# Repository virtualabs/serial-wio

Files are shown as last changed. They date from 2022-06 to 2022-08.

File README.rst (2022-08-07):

Serial-Wio
==========

Turn your WioTerminal into an automagic UART terminal !

Features
--------

* Automatic baudrate/parity detection
* On-screen UART log
* USB UART bridge

Case printing and assembly
--------------------------

A custom case has been designed to fit the WioTerminal, it allows normal multimeter probes
to be used and protects the electronics.

The case is made of 3 independent parts that may be 3d printed with any decent 3d printer:

* a bottom part that holds 6 M3 hex screws
* a middle part that holds 2 M3 hex nuts
* a top part

Extra materials required:

* 2x 10mm M3 screws
* 4x 15mm M3 screws
* 2x M3 nuts

Printing the case
~~~~~~~~~~~~~~~~~

Top part must be printed upside down to get best results, without supports. Bottom part must be
printed with supports to get the screws' heads holes correctly printed.

Assembling the case
~~~~~~~~~~~~~~~~~~~

First, insert 2x 10mm M3 screws in the bottom part as shown below:

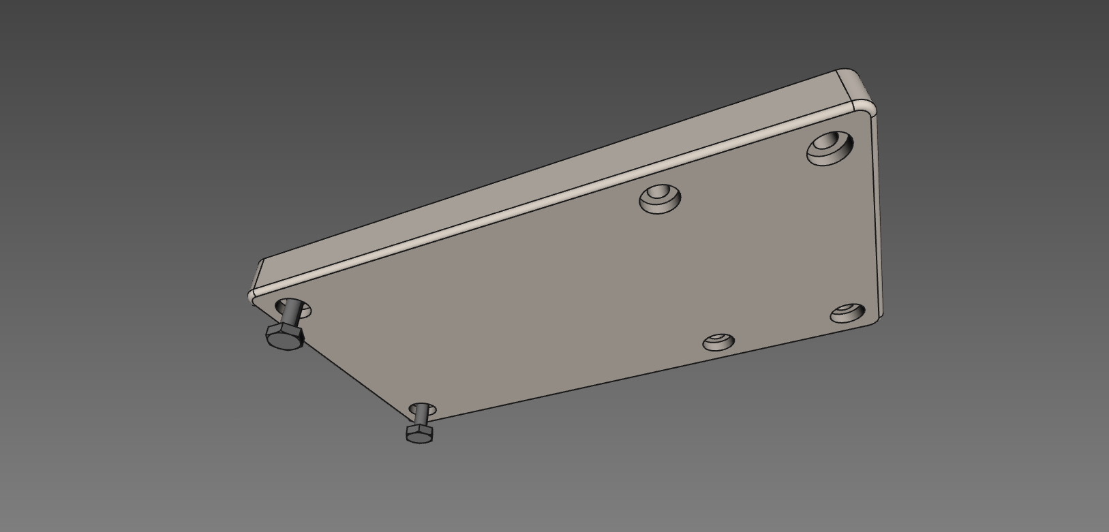
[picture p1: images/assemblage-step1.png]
Assembling bottom part


Then, place the custom PCB inside the bottom part:

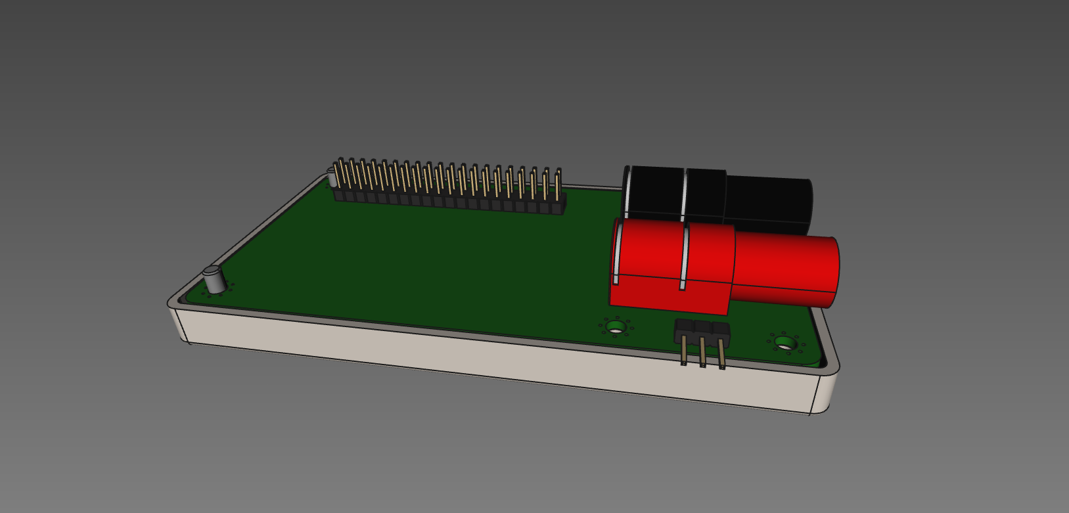
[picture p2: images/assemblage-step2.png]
Insert Serial-Wio assembled PCB


Place on top of this the intermediate lid and add two M3 nuts. Tighten them just enough to hold the lid
in place. 

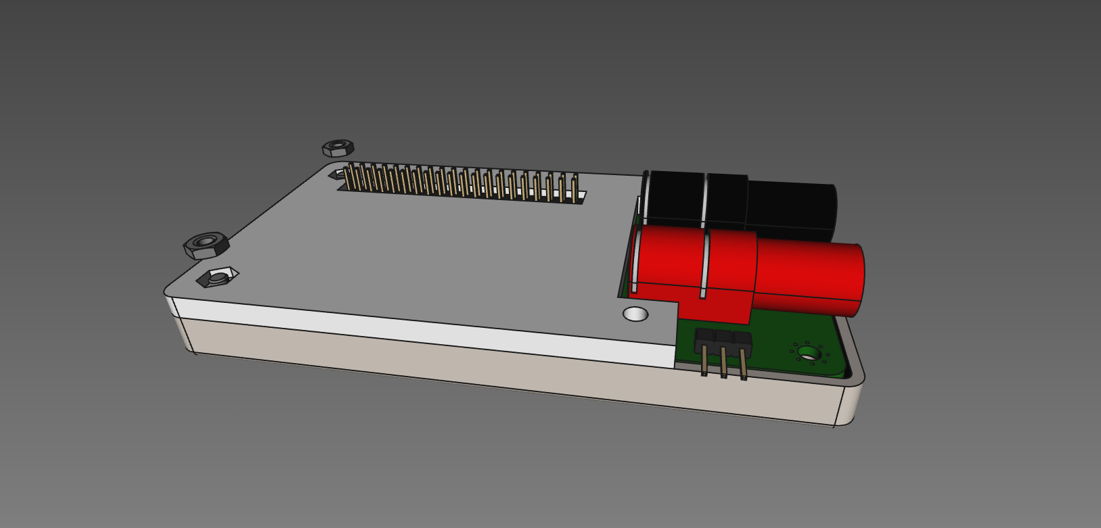
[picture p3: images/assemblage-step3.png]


Last, place the top lid and screw 4x 15mm M3 screws to maintain it in place, as shown below:

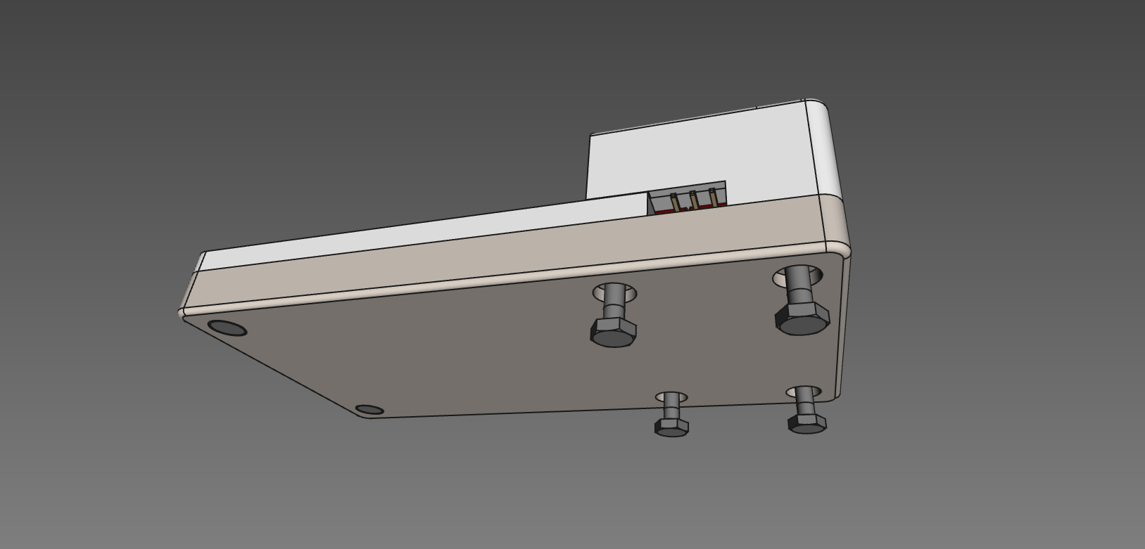
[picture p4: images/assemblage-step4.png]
Fix the top lid


You can now connect your WioTerminal to your SerialWio module:

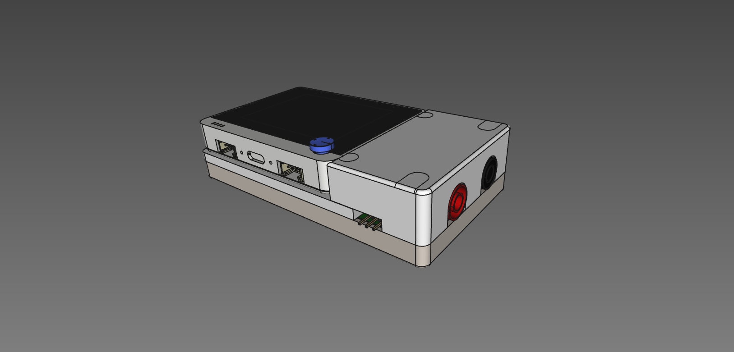
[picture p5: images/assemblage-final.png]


Custom PCB
----------

We designed a custom PCB that extends WioTerminal capabilities designed with KiCAD v5.
Design files are available in `PCB_design_files` folder, including 3D models and custom
fingerprints.

Gerber files
~~~~~~~~~~~~

Gerber files are also provided in the `PCB_design_files/gerber` directory, as well as the
`kicad_pcb` file if you want to order it on OSHPark. 

Bill of materials
~~~~~~~~~~~~~~~~~

* Q1, Q2, Q3: SOT23 MMBF170 N-channel MOSFET 60V 225mW (Ref LCSC: C130879)
* R1, R2, R3: R0805 10 Kohm (Ref LCSC: C269742)
* TEST_SIG1: 4mm banana female plug red (Farnell: SWEB 8094 AU/RT)
* TEST_GND1: 4mm banana female plug black (Farnell: SWEB 8094 AU/SW)
* 3 contacts (1 row) 2.54mm right-angled header

Software dependencies
---------------------

First, you need to follow the `Get Started with Wio Terminal <https://wiki.seeedstudio.com/Wio-Terminal-Getting-Started/>`_
guide in order to setup your Arduino development environment.

This project has been designed with Arduino and requires some libraries to successfully compile:

* `TFT_eSPI` to drive the LCD screen of the WioTerminal
* `SAMD_TimerInterrupt` to handle SAMD21 timers

Make sure to add them before trying to compile the import the Arduino sketch and build it (use Arduino's
library manager).

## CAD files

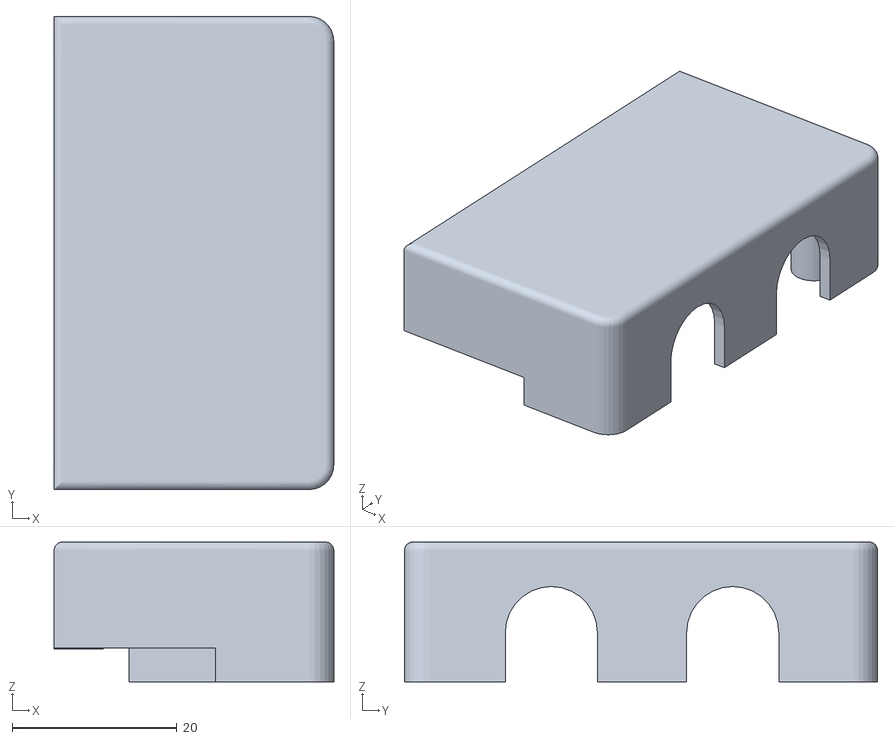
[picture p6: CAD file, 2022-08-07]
Case_design_files/case-top-part.stl
34.0 x 57.5 x 17.0

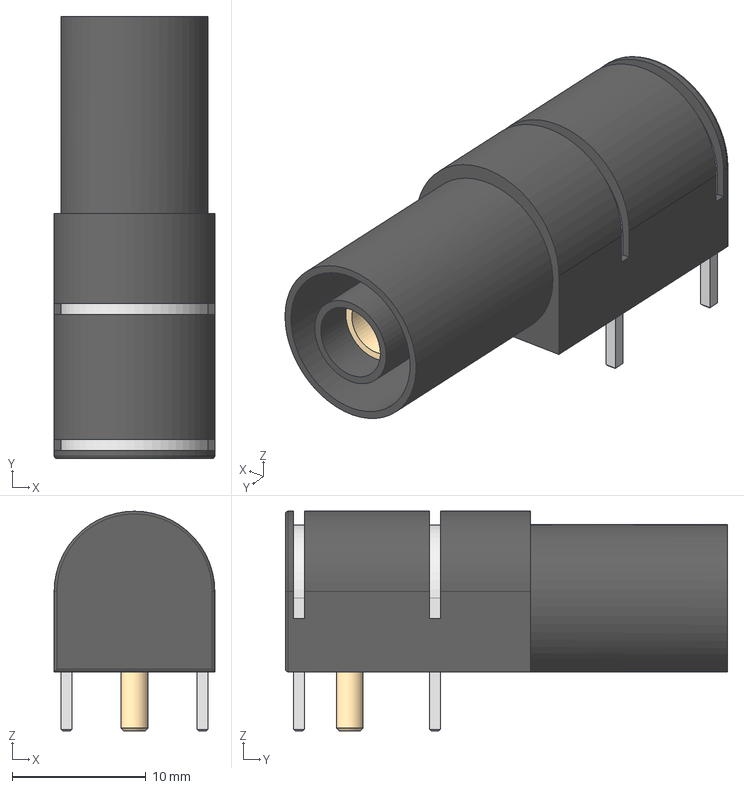
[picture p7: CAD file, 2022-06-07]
PCB_design_files/3d/4mm-test-conn-socket-black.step
12.0 x 33.0 x 16.4 mm
Corps principal
Anneau intérieur
Pin verticale 1
Pin verticale 2
Pin principale

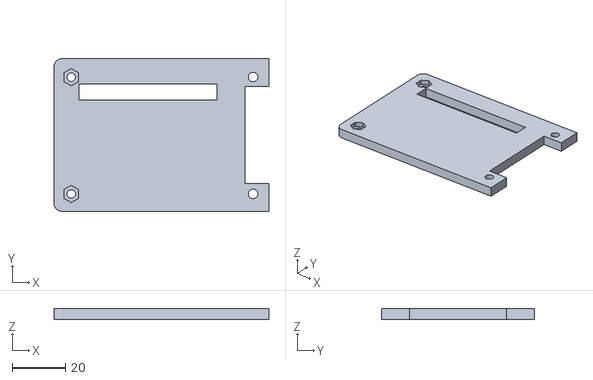
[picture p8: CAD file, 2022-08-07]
Case_design_files/case-intermediate-lid-part.stl
81.0 x 57.5 x 4.00

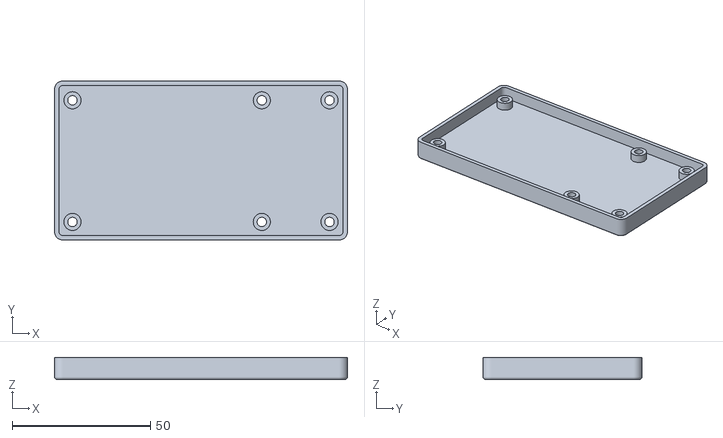
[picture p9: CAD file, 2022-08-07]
Case_design_files/case-bottom-part.stl
106.0 x 57.5 x 8.00

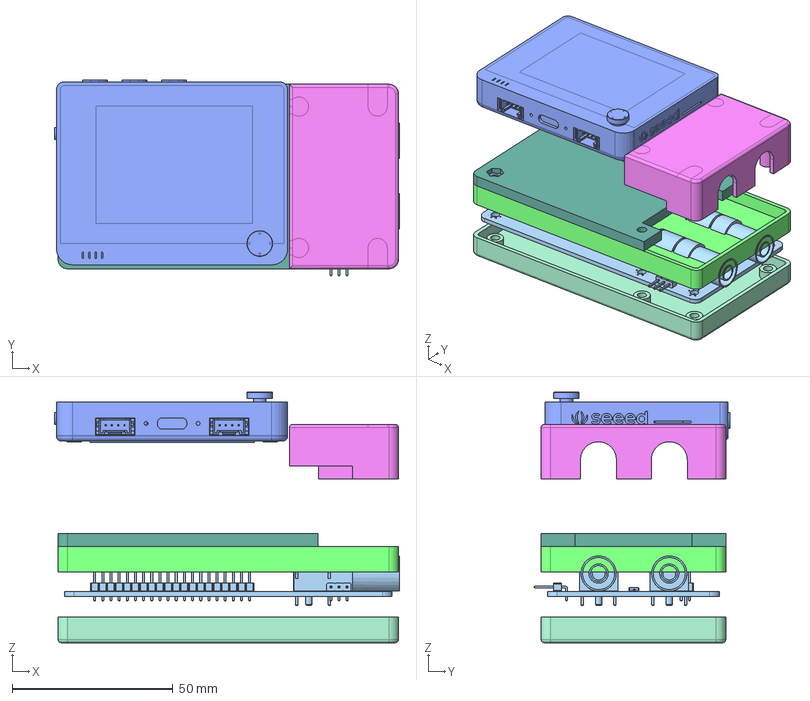
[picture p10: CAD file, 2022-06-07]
Case_design_files/serial-wio-case.FCStd
107.4 x 60.9 x 78.0 mm
Wio Terminal
Capot intermédiaire
Capot connecteurs
Pocket008Body
serial-wio

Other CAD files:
PCB_design_files/3d/4mm-test-conn-socket-red.step
PCB_design_files/3d/4mm-test-conn-socket.step
PCB_design_files/3d/4mm-test-conn-socket.FCStd

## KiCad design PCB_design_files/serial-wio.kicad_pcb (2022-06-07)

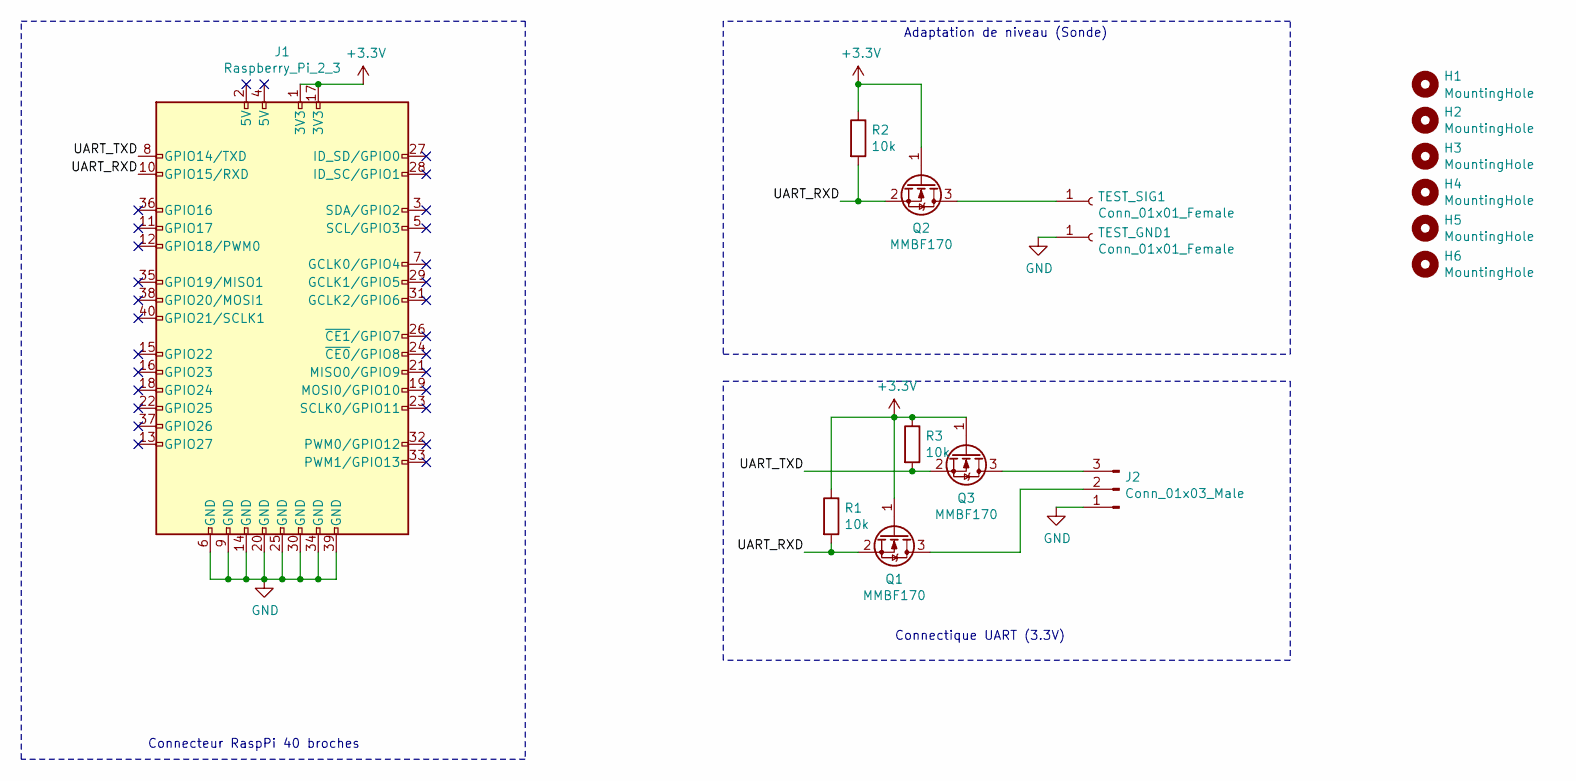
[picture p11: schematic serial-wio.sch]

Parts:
H1, H2, H3, H4, H5, H6: MountingHole; MountingHole_3.2mm_M3_Pad_Via
J1: Raspberry_Pi_2_3; PinHeader_2x20_P2.54mm_Vertical
J2: Conn_01x03_Male; PinHeader_1x03_P2.54mm_Horizontal
Q1, Q2, Q3: MMBF170; SOT-23
R1, R2, R3: 10k; R_0805_2012Metric
TEST_GND1: Conn_01x01_Female; 4mm-test-conn-socket
TEST_SIG1: Conn_01x01_Female; 4mm-test-conn-socket

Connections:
+3V3: J1.1 (3V3), J1.17 (3V3), Q1.1 (G), Q2.1 (G), Q3.1 (G), R1.1, R2.1, R3.1
/UART_RXD: J1.10 (GPIO15/RXD), Q1.2 (S), Q2.2 (S), R1.2, R2.2
/UART_TXD: J1.8 (GPIO14/TXD), Q3.2 (S), R3.2
GND: J1.6 (GND), J1.9 (GND), J1.14 (GND), J1.20 (GND), J1.25 (GND), J1.30 (GND), J1.34 (GND), J1.39 (GND), J2.1, TEST_GND1.1
unnamed: J2.2, Q1.3 (D)
unnamed: J2.3, Q3.3 (D)
unnamed: Q2.3 (D), TEST_SIG1.1

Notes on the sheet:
Connecteur RaspPi 40 broches
Adaptation de niveau (Sonde)
Connectique UART (3.3V)

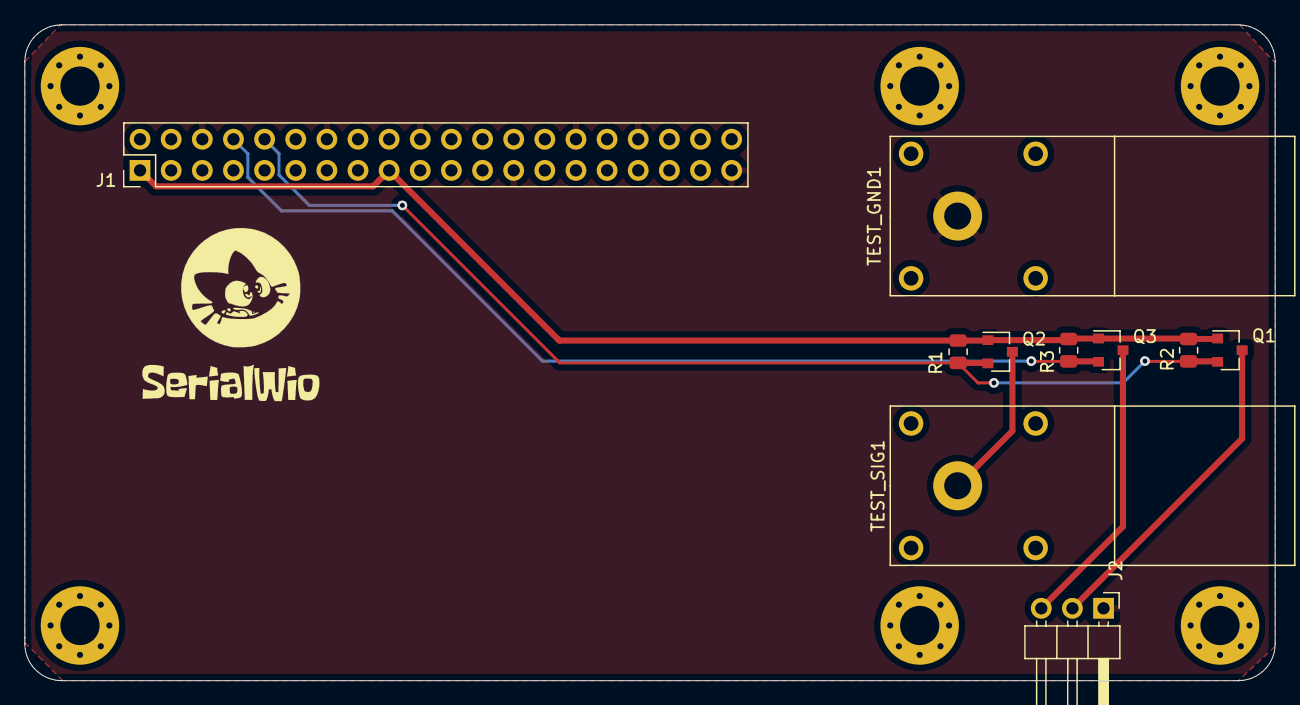
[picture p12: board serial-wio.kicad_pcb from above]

Board: 2 copper layers, 102.0 x 53.5 mm, 17 parts (0 on the bottom side), 7 nets.

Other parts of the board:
kibuzzard-62313C45: G***; label

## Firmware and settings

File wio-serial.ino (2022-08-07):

#include "SAMDTimerInterrupt.h"
#include"TFT_eSPI.h"

#define BUZZER_PIN WIO_BUZZER /* sig pin of the buzzer */

#define MAX_MEASURES    5000
#define IDLE_INTERVAL   100000
#define PROBE_INPUT     PIN_SERIAL1_RX
#define SCREEN_WIDTH    50
#define SCREEN_HEIGHT   22
#define LINE_HEIGHT     10
#define LOG_OFFSET_Y    (2*LINE_HEIGHT)

#define BG_COLOR        TFT_BLACK
#define TEXT_COLOR      TFT_LIGHTGREY

/*********************
 * Typedefs
 *********************/

typedef enum {
  WAITING,
  ACQUIRE,
  ANALYZE,
  MONITOR
} mp_state_t;

enum {
  PAR_NONE = 0,
  PAR_ODD,
  PAR_EVEN,
  PAR_MAX
};

typedef struct {
  int period;
  int baudrate;
} baudrate_info_t;

/**********************
 * Globals
 **********************/

/* Global state. */
volatile mp_state_t g_state;

/* Logic analysis. */
static uint32_t g_measures[MAX_MEASURES];
volatile uint32_t g_usec_counter;
volatile uint32_t g_last_timestamp;
volatile int g_nb_measures;
volatile int baudrate = 0, uart_config, good_par, g_bytesize;

/* Timer. */
SAMDTimer ITimer0(TIMER_TC3);

/* Screen. */
TFT_eSPI tft;
char g_uart_log[SCREEN_HEIGHT][SCREEN_WIDTH+1];
int g_uart_cur_col, g_uart_cur_line, g_uart_top_line;



/**********************************************
 **********************************************
 *
 * Helpers
 * 
 **********************************************
 **********************************************/

/**
 * @brief Convert period to standard baudrate
 * @param period: measured period in microseconds
 * @return closest standard baudrate
 */
int period_to_baudrate(int period)
{
  int i=0;
  baudrate_info_t rates[] = {
    {4, 230400},
    {8, 115200},
    {13, 76800},
    {17, 57600},
    {26, 38400},
    {34, 28800},
    {52, 19200},
    {104, 9600},
    {0, 0}
  };

  while (rates[i].period > 0)
  {
    if ( period <= (rates[i].period+1))
    {
      return rates[i].baudrate;
    }
    i++;
  }

  /* Not found, return -1. */
  return -1;
}


/**
 * @brief Count printable characters
 * @param p_data: pointer to an array of characters
 * @param data_size: number of characters in the given array
 * @return number of printable characters
 */

int count_printable_chars(char *p_data, int data_size)
{
  int count=0;
  for (int i=0; i<data_size; i++)
  {
    if (isPrintable(p_data[i]))
      count++;
  }

  return count;
}


/**
 * @brief uSec counter callback (used for logic analysis).
 **/

void u_sec_counter(void)
{
  /* Increment our counter. */
  g_usec_counter++;

  /* Detect if we detect an idling UART. */
  if ((g_state == ACQUIRE) && ((g_usec_counter - g_last_timestamp) > IDLE_INTERVAL))
  {
    g_state = ANALYZE;
  }
}

/**
 * @brief Play tone.
 * @param tone: tone to play (Hz)
 * @param duration: tone duration (milliseconds)
 **/

void playTone(int tone, int duration) {
    for (long i = 0; i < duration * 1000L; i += tone * 2) {
        digitalWrite(BUZZER_PIN, HIGH);
        delayMicroseconds(tone);
        digitalWrite(BUZZER_PIN, LOW);
        delayMicroseconds(tone);
    }
}


/**********************************************
 **********************************************
 *
 * Screen management
 * 
 **********************************************
 **********************************************/

/**
 * @brief Clear UART log screen
 */

void clear_log_screen(void)
{
  /* Clear screen buffer. */
  memset(g_uart_log, 0, (SCREEN_WIDTH+1)*SCREEN_HEIGHT);
  g_uart_cur_line = 0;
  g_uart_cur_col = 0;
  g_uart_top_line = 0;

  /* Clear screen. */
  tft.fillRect(0, LOG_OFFSET_Y, 320, 240 - LOG_OFFSET_Y, BG_COLOR);
}


/**
 * @brief Update status bar (in MONITOR mode)
 */
 
void update_status_bar(void)
{
  char parity[] = "NOE";
  char sz_baudrate[10];
  char sz_config[4];
  snprintf(sz_baudrate, 10, "%d", baudrate);
  snprintf(sz_config, 4, "%d%c1", g_bytesize, parity[good_par]);
  
  tft.fillRect(0, 0, 320, LOG_OFFSET_Y-2, TFT_DARKGREEN);
  tft.setTextSize(2);
  tft.drawString(sz_baudrate, 5, 2);
  tft.drawString(sz_config, 90, 2);
  tft.setTextSize(1);
}


/**
 * @brief Update measures bar (in WAITING mode)
 */
 
void update_waiting_measures(void)
{
  int prog = (g_nb_measures * 150.0)/MAX_MEASURES;
  tft.drawRect(85, 125, 150, 10, TFT_NAVY);
  tft.fillRect(86, 126, prog,8, TFT_NAVY);
}


/**
 * @brief Update our waiting screen (in WAITING mode)
 */
 
void wait_screen(void)
{
  tft.fillRect(0, 0, 320, 240,BG_COLOR);
  tft.fillRect(80, 90, 160, 60, TFT_DARKGREY);
  tft.setTextSize(2);
  tft.drawString("Syncing ...", 85, 95);
  tft.setTextSize(1);

  update_waiting_measures();
}


/**********************************************
 **********************************************
 *
 * User button callbacks
 * 
 **********************************************
 **********************************************/

/**
 * @brief Resync button callback
 **/
 
void resync_button_pressed(void)
{
  /* No effect if we are currently syncing ... */
  if (g_state == WAITING)
    return;
  
  /* Debounce */
  delay(10);
  if (digitalRead(WIO_KEY_C) != 0)
    return;
  
  /* Setup our input GPIO. */
  Serial1.end();
  attachInterrupt(digitalPinToInterrupt(PROBE_INPUT), track_state, CHANGE);
  
  /* Restart analysis. */
  g_state = WAITING;

  /* Reset measures. */
  g_nb_measures = 0;

  /* Reset counter. */
  g_usec_counter = 0;
  g_last_timestamp = 0;

  /* Reset screen. */
  wait_screen();
}


/**
 * @brief Clear screen button callback
 **/

void clear_button_pressed(void)
{
  if (g_state == MONITOR)
  {
    /* Debounce */
    delay(10);
    if (digitalRead(WIO_KEY_A) != 0)
      return;

    clear_log_screen();
  }
}


/**********************************************
 **********************************************
 *
 * Signal acquisition callback (timer)
 * 
 **********************************************
 **********************************************/

/**
 * @brief Track state of input probe.
 * 
 * Fills g_measures with timestamps.
 */

void track_state(void)
{
  switch(g_state)
  {
    case WAITING:
      {
        /* Found a falling edge, start acquisition. */
        if (digitalRead(PROBE_INPUT) == 0)
        {
          /* Save measure. */
          g_nb_measures = 0;
          g_measures[g_nb_measures++] = g_usec_counter;
          g_last_timestamp = g_usec_counter;
          
          /* Set mode to ACQUIRE. */
          g_state = ACQUIRE;
        }
      }
      break;

    case ACQUIRE:
      {
        /* Save measure if we have enough memory. */
        if (g_nb_measures < MAX_MEASURES)
        {
          /* Save measure. */
          g_measures[g_nb_measures++] = g_usec_counter;
          g_last_timestamp = g_usec_counter;
        }
        else
        {
          Serial.println("> Switching to analysis");
          /* Switch to analyze mode. */
          g_state = ANALYZE;
        }
      }
      break;
  }
}
 

/**********************************************
 **********************************************
 *
 * Main code
 * 
 **********************************************
 **********************************************/

/**
 * @brief Setup routine (initializes the WioTerminal)
 */
 
void setup() {
  /* Setup WioTerminal Serial. */
  Serial.begin(115200);

  /* Setup screen. */
  tft.begin();
  tft.setRotation(3);
  tft.fillScreen(BG_COLOR); //Red background
  tft.setTextColor(TEXT_COLOR);          //sets the text colour to black
  tft.setTextSize(1);                   //sets the size of text

  /* Clear screen. */
  clear_log_screen();

  /* Setup our buttons. */
  pinMode(WIO_KEY_A, INPUT_PULLUP);
  pinMode(WIO_KEY_C, INPUT_PULLUP);
  attachInterrupt(digitalPinToInterrupt(WIO_KEY_A), clear_button_pressed, FALLING);
  attachInterrupt(digitalPinToInterrupt(WIO_KEY_C), resync_button_pressed, FALLING);
 
  /* Setup our input GPIO. */
  Serial1.end(); // Disable hardware UART
  pinMode(PROBE_INPUT, INPUT);
  attachInterrupt(digitalPinToInterrupt(PROBE_INPUT), track_state, CHANGE);

  /* Setup our buzzer. */
  pinMode(WIO_BUZZER, OUTPUT);

  /* Set default state. */
  mp_state_t g_state = WAITING;
  g_nb_measures = 0;

  /* Set our timer. */
  g_usec_counter = 0;

  /* Start timer (call u_sec_counter each microsecond. */
  ITimer0.attachInterruptInterval(1, u_sec_counter);

  /* Display wait screen. */
  wait_screen();
}


/**
 * @brief Try to decode a captured signal based on possible UART parameters.
 * @param period: period used to reconstruct the UART frame (number of samples per bit)
 * @param nbits: number of bits to code 1 'byte'
 * @param bit_duration: duration of 1 bit in microsecond (used to compute baudrate)
 * @param parity: parity (none, odd, even)
 * @param p_data: pointer to an output buffer
 * @param p_data_size: pointer to the size of the output buffer
 * @return number of encountered errors.
 */
 
int try_decode(int period, int nbits, int bit_duration, int parity, char *p_data, int *p_data_size)
{
  int i,j,bitpos,m,ones,errors;
  uint8_t state=1;
  uint8_t bits[10];
  unsigned char b;
  uint32_t tzero;
  bool b_parity_enabled = false;
  int nbytes;
  
  enum {
    START,
    DATA,
    PARITY,
    STOP
  };
  
  uint8_t decode_state = STOP;
    
  /* bit duration. */
  //const double t = 1000000.0/baudrate;
  const double t = bit_duration;
  double t_off = 0.0;
  tzero = g_measures[0]; /* timestamp du startbit, en usec */

  /* Determine parity bit size. */
  if (parity != PAR_NONE)
  {
    b_parity_enabled = true;
  }
  
  /* No errors encountered yet. */
  errors = 0;
  nbytes = 0;

  i=0;
  m=0;
  t_off = tzero;
  while (m < g_nb_measures)
  {
    /* track state change. */
    if (t_off >= g_measures[m])
    {
      /* Tuning. */
      tzero = g_measures[m];
      i = 0;
      
      //Serial.println("-- state change detected");
      state = (~state)&1;
      m++;
      
      /* Falling edge: start bit. */
      if ((decode_state == STOP) && !state)
      {
        //Serial.println("Falling edge, start bit detected.");
        decode_state = START;
      }
    }
    
    /* save bit. */
    if (t_off > (tzero + i*t + t/2) )
    {
      switch(decode_state)
      {
        case DATA:
          {
            bits[bitpos++] = state;

            if (bitpos >= (nbits + ((b_parity_enabled)?1:0)))
            {
              /* parity not supported yet, goto stop bit. */
              decode_state = STOP;

              /* Decode byte and display. */
              b=0;
              ones=0;
              for (j=0; j<nbits; j++)
              {
                /* Count 1's. */
                if (bits[j]&1)
                  ones++;

                /* Compute byte. */
                b |= ((bits[j]&1) << j);
              }

              /* Check parity if required. */
              if (b_parity_enabled)
              {
                switch(parity)
                {
                  case PAR_ODD:
                    {
                      if (bits[nbits] != ((ones%2)==0)?1:0)
                        errors++;
                    }
                    break;

                  case PAR_EVEN:
                    {
                      if (bits[nbits] != (ones%2))
                        errors++;
                    }
                    break;
                  
                  default:
                    break;
                }
              }

              /* Save decoded byte. */
              if (nbytes < *p_data_size)
              {
                p_data[nbytes++] = b;
              }
              else
              {
                /* Return the number of bytes written. */
                *p_data_size = nbytes;
              
              
                /* Return number of errors. */
                return errors;
              }
              
            }
          }
          break;
          
          
        case START:
          {
            decode_state = DATA;
            bitpos = 0;
          }
          break;

        default:
          break;
      }

      i++;
    }
    
    t_off += period;
  }

  /* Return the number of bytes written. */
  *p_data_size = nbytes;


  /* Return number of errors. */
  return errors;
}

/**
 * Main loop.
 */

void loop() {
  uint32_t min_inter, delta, i, total, nbits, bytesize;
  char rx_data[10];
  int bufsize;
  int parity, printable, found;
  int nbytes;
  char rx_buf[SCREEN_WIDTH];
  char rx_byte;

  switch(g_state)
  {
    case WAITING:
    case ACQUIRE:
    {
      /* Update nb measures. */
      update_waiting_measures();
    }
    break;
    
    case ANALYZE:
    {
      /* Determine bit duration. */
      min_inter = g_last_timestamp;
      
      /* Look for minimum interval (1 bit coded). */
      for (i=0; i<(g_nb_measures-1); i++)
      {
        delta = g_measures[i+1] - g_measures[i];
        if (delta < min_inter)
          min_inter = delta;
      }
  
      
      Serial.print("Bit duration: ");
      Serial.println(min_inter);
      
  
      /* Bruteforce parameters. */
      found = 0;
      for (bytesize=7; bytesize<9; bytesize++)
      {
        good_par = PAR_NONE;
        for (parity=PAR_NONE; parity<PAR_MAX; parity++)
        {
          bufsize = 10;
          if (try_decode(min_inter/4, bytesize, min_inter, parity, rx_data, &bufsize) == 0)
          {
            /* All characters are printable: found it ! */
            printable = count_printable_chars(rx_data, bufsize);
            if (printable == bufsize)
            {
              found = 1;
              
              /* Keep the best parity setting. */
              if (parity != PAR_NONE)
                good_par = parity;
            }
          }
        }
  
        /* Display parameters if found. */
        if (found)
        {
          g_bytesize = bytesize;
          
          Serial.print("Bit duration (us): ");
          Serial.println(min_inter);
          Serial.print("Byte size: ");
          Serial.println(bytesize);
          Serial.print("Parity: ");
          switch (good_par)
          {
            case PAR_NONE:
              Serial.println("none");
              uart_config = (bytesize - 5)*2;
              break;
  
            case PAR_EVEN:
              Serial.println("even");
              uart_config = (bytesize - 5)*2 + 0x20;
              break;
  
            case PAR_ODD:
              Serial.println("odd");
              uart_config = (bytesize - 5)*2 + 0x30;
              break;
          }
          baudrate = period_to_baudrate(min_inter);
          Serial.print("Baudrate: ");
          Serial.println(baudrate);
          Serial.print("UART config: ");
          Serial.println(uart_config, HEX);
        }
      }
  
      /* UART parameters recovered, configure hardware UART. */
      if ((found) && (baudrate > 0))
      {
        Serial.println("======< MONITOR >=============");
        
        /* Switch to display mode. */
        g_state = MONITOR;

        g_nb_measures = MAX_MEASURES;
        update_waiting_measures();

        /* Beeeeep. */
        playTone(1915, 100);

        /* Clear screen. */
        tft.fillRect(0, 0, 320, 240,BG_COLOR);

        /* Update status bar: display baudrate and config. */
        update_status_bar();
        clear_log_screen();

        /* Re-enable hardware UART. */
        detachInterrupt(digitalPinToInterrupt(PROBE_INPUT));
        Serial1.begin(baudrate, uart_config);
      }
      else
      {
        Serial.println("> Switch to acquisition mode");
        /* Back to waiting. */
        g_state = WAITING;
      }
    }
    break;

    case MONITOR:
    {
      /* Read data from UART. */
      nbytes = Serial1.available();
      if (nbytes > 0)
      {
        if (nbytes > SCREEN_WIDTH)
          nbytes = SCREEN_WIDTH;
        rx_byte = Serial1.readBytes(rx_buf, nbytes);
        /* Forward to Serial. */
        Serial.write(rx_buf, nbytes);

        /* Store data in memory. */
        for (i=0; i<nbytes; i++)
        {
          /* Jump to next line if '\n' received. */
          if (rx_buf[i] == '\n')
          {
            /* Update display. */
            tft.fillRect(0, g_uart_cur_line*LINE_HEIGHT + LOG_OFFSET_Y, 320, LINE_HEIGHT, BG_COLOR);
            tft.drawString(g_uart_log[g_uart_cur_line], 0, g_uart_cur_line*LINE_HEIGHT + LOG_OFFSET_Y);
            
            g_uart_cur_line = (g_uart_cur_line + 1) % SCREEN_HEIGHT;

            if (g_uart_cur_line == g_uart_top_line)
            {
              g_uart_top_line = (g_uart_top_line + 1) % SCREEN_HEIGHT;
              memset(&g_uart_log[g_uart_cur_line], 0, SCREEN_WIDTH+1);
            }
          }
          else if (rx_buf[i] == '\r')
          {
            g_uart_cur_col = 0;
          }
          else
          {
            if (g_uart_cur_col < SCREEN_WIDTH)
            {
              g_uart_log[g_uart_cur_line][g_uart_cur_col++] = rx_buf[i];
            }
          }
        }

        /* Update display. */
        tft.fillRect(0, g_uart_cur_line*LINE_HEIGHT + LOG_OFFSET_Y, 320, LINE_HEIGHT, TFT_RED);
        tft.drawString(g_uart_log[g_uart_cur_line], 0, g_uart_cur_line*LINE_HEIGHT + LOG_OFFSET_Y);
      }
    }
    break;

    default:
      break;
  }
}

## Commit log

2022-06-07 Added PCB and custom case design files.
    [4mm-test-conn-socket-black.step, 4mm-test-conn-socket-red.step, 4mm-test-conn-socket.FCStd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]
2022-08-07 Added STL files and updated arduino code.
    [case-bottom-part.stl, case-intermediate-lid-part.stl, case-top-part.stl]
2022-08-07 Added BOM
